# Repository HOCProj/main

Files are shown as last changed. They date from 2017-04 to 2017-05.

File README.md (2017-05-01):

**HOC Project**

*Hutchins-O'Dell-Cooper Senior Design Project Repository*

This project uses the following libraries and guides:

Adafruit MCP3008 library:
https://github.com/adafruit/Adafruit_Python_MCP3008

Twython AND Oauth:
https://www.raspberrypi.org/learning/getting-started-with-the-twitter-api/requirements/software/
https://www.raspberrypi.org/forums/viewtopic.php?t=162900&p=1054189

AVRDude:
http://www.raspihub.com/go/4c3370e8431b091c1698106135127581a646f3e2829fc26123d2bbfb34199dfa

SSMPT (Send email):
http://stackoverflow.com/questions/38391412/raspberry-pi-send-mail-from-command-line-using-gmail-smtp-server

Fetchmail (Receive email):
http://www.raspberry-projects.com/pi/software_utilities/email/fetchmail-to-receive-email

These libraries will be automatically downloaded and installed by executing the GitAll.py file. After installation, some parts require additional setup. Refer to the corresponding guide.

**User Manual**

Setup guides and example scripts are available in the appropriate folders (Raspberry Pi and ATTiny85).

The primary purpose of our project is to provide a cheap means of extending the capabilities of the Raspberry Pi and the ATTiny85. We also have the secondary purpose of compiling all of the necessary software and troubleshooting into one location, so that a person with beginner-intermediate level experience with circuitry and code can avoid the wiring mess of traditional electronics and the days or weeks of research into software.

On the board is a 40-pin header. This is used to connect our project to the Raspberry Pi. Doing so gives the Pi access to an MCP3008 ADC and an external power supply. There is also an 8-pin socket for an ATTiny85, which can be connected and interfaced with the IR receiver and the external power supply and ADC as well. The Raspberry Pi and ATTiny85 can be used simultaneously or separately. If using both of them and the ADC for either (cannot be used by both at one time), you must be mindful of shared connections. Refer to the board schematics.

A green screw block connector is situated next to the IR receiver. This can be used to receive external power (up to 33V and 3A continuous), and regulate it to ~5V for the Pi and ATTiny. Next to that is an 8-pin straight header. These are the analog inputs for the ADC, corresponding to channels 0-7. Next to that is a 2x4-pin header, which is laid out exactly the same as the ATTiny85 pins and is used to access those pins. Below that is a button which resets the ATTiny85 (pulls the RESET pin to ground).

There are two 2-pin headers, each labeled RPi and MCP. These are used to connect and disconnect power to the Raspberry Pi and MCP3008 respectively. If, for example, you want the ATTiny and Raspberry Pi to communicate over the ISP lines, the MCP header should be disconnected to prevent that chip from interfering with the signals. Or if you want the ATTiny to use the ADC and the Pi is not in use or powered separately, the RPi header should be disconnected.]

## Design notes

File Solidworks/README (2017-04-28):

This folder contains Solidworks and .STL models of the case parts.

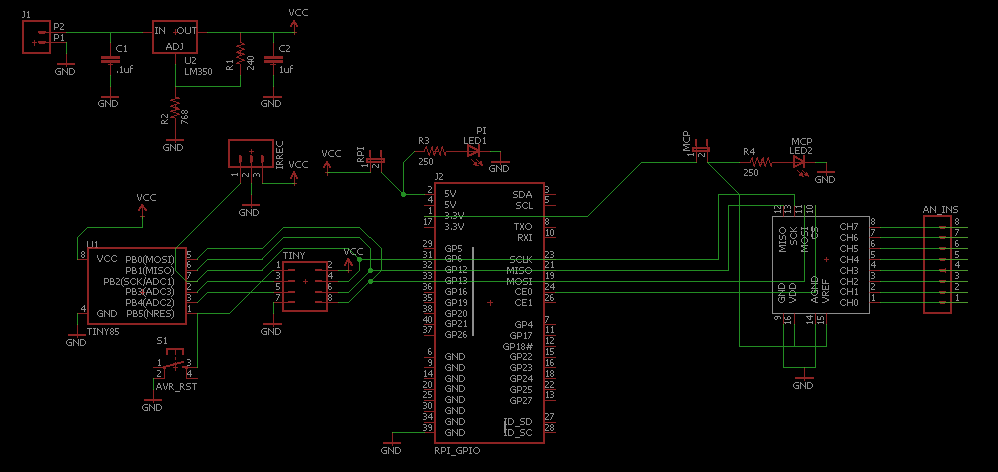
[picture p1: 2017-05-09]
Schematic Rev 2.png

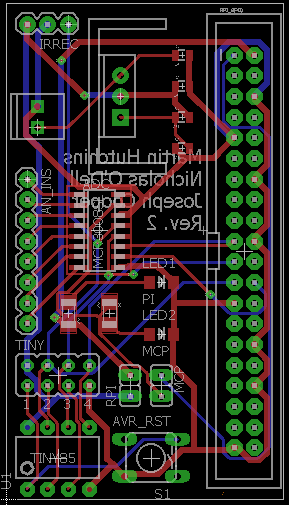
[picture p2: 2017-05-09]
Board Rev 2.png

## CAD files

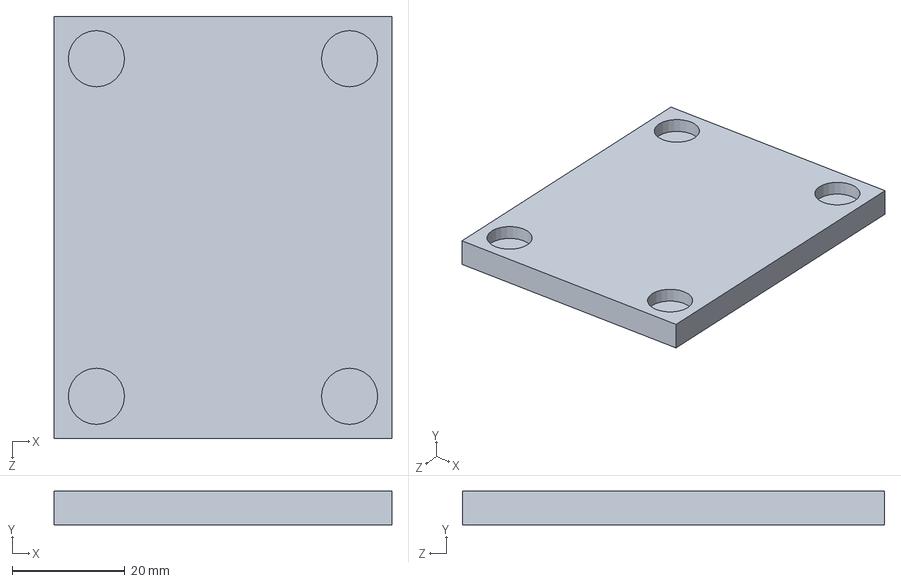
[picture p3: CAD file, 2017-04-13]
Solidworks/top.SLDPRT
60.0 x 6.00 x 75.0 mm

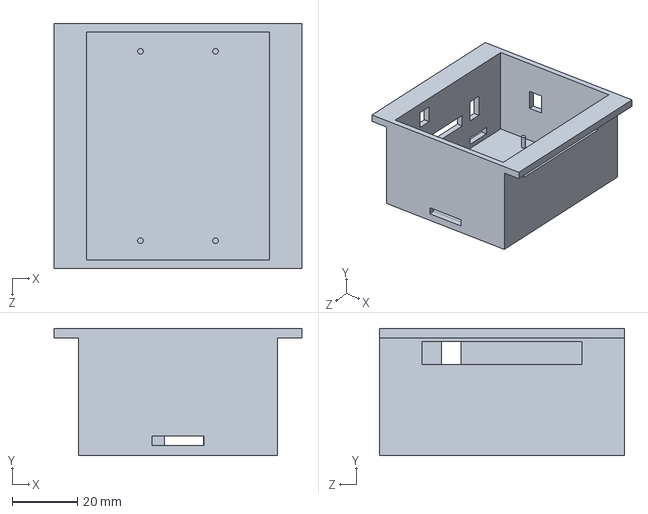
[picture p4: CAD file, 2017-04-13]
Solidworks/part 2 with pegs.SLDPRT
76.0 x 39.0 x 75.0 mm

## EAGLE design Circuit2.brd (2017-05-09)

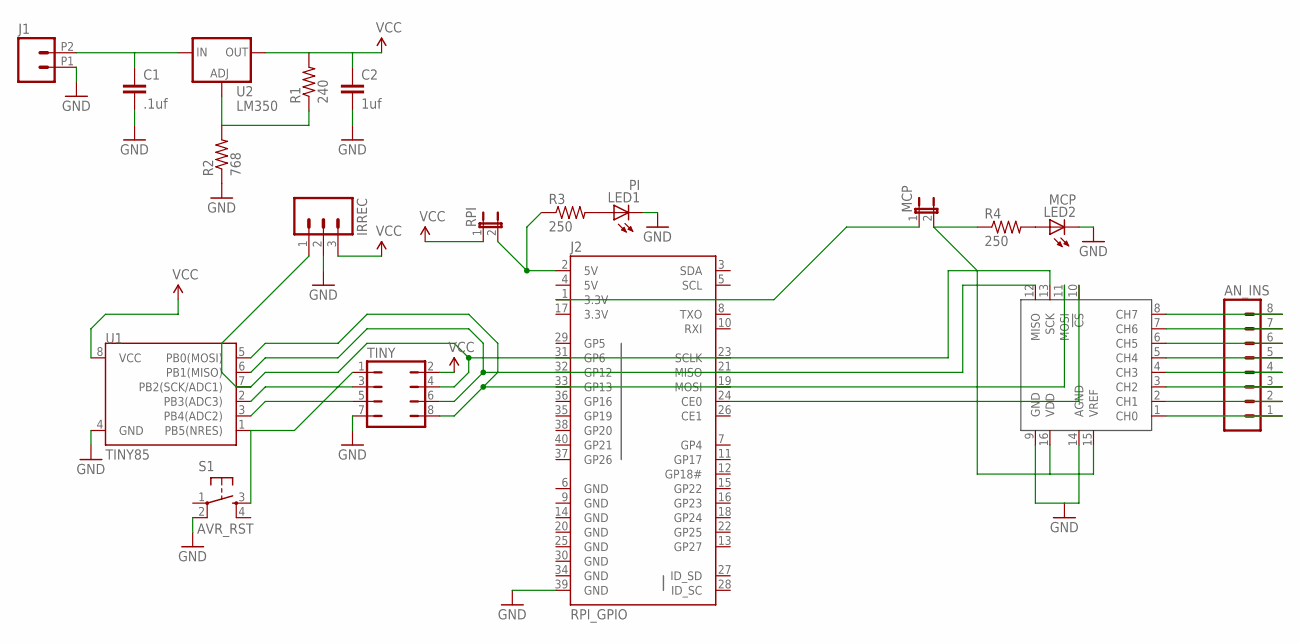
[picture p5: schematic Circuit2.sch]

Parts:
ADC: MCP3008SL; SO16
AN_INS: M08; 1X08_ROUND
C1: .1uf; 0805
C2: 1uf; 0805
IRREC: M03PTH; 1X03
J1: M022.54MM_SCREWTERM; 1X02_2.54_SCREWTERM
J2: RPI_GPIO; 2X20-SHROUDED
LED1: PI; LED-1206
LED2: MCP; LED-1206
MCP: JP1E; JP1
R1: 240; 0805
R2: 768; 0805
R3, R4: 250; 1206
RPI: JP1E; JP1
S1: AVR_RST; TAC-SWITCH-PTH
TINY: JP4Q
U1: TINY85; DIP08
U2: LM350; TO220-ADJ

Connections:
3.3V: J2.17 (3.3V)
5V: J2.4 (5V)
GND: ADC.9 (GND), ADC.14 (AGND), C1.2, C2.2, IRREC.2, J1.P1 (1), J2.6 (GND), J2.9 (GND), J2.14 (GND), J2.20 (GND), J2.25 (GND), J2.30 (GND), J2.34 (GND), J2.39 (GND), LED1.C, LED2.C, R2.1, S1.2, TINY.7, U1.4 (GND)
unnamed: ADC.11 (MOSI), J2.19 (MOSI), TINY.8, U1.5 (PB0(MOSI))
unnamed: ADC.12 (MISO), J2.21 (MISO), TINY.6, U1.6 (PB1(MISO))
unnamed: ADC.13 (SCK), IRREC.1, J2.23 (SCLK), TINY.4, U1.7 (PB2(SCK/ADC1))
unnamed: J2.2 (5V), R3.1, RPI.2
unnamed: TINY.3, U1.2 (PB3(ADC3))
unnamed: S1.3, TINY.1, U1.1 (PB5(NRES))
unnamed: TINY.5, U1.3 (PB4(ADC2))
unnamed: ADC.15 (VREF), ADC.16 (VDD), MCP.2, R4.1
unnamed: R1.1, R2.2, U2.ADJ
unnamed: ADC.8 (CH7), AN_INS.8
unnamed: C1.1, J1.P2 (2), U2.IN
unnamed: ADC.10 (!CS), J2.24 (CE0)
unnamed: J2.1 (3.3V), MCP.1
unnamed: ADC.7 (CH6), AN_INS.7
unnamed: ADC.6 (CH5), AN_INS.6
unnamed: ADC.5 (CH4), AN_INS.5
unnamed: ADC.4 (CH3), AN_INS.4
unnamed: ADC.3 (CH2), AN_INS.3
unnamed: ADC.2 (CH1), AN_INS.2
unnamed: ADC.1 (CH0), AN_INS.1
unnamed: LED1.A, R3.2
unnamed: LED2.A, R4.2
VCC: C2.1, IRREC.3, R1.2, RPI.1, TINY.2, U1.8 (VCC), U2.OUT

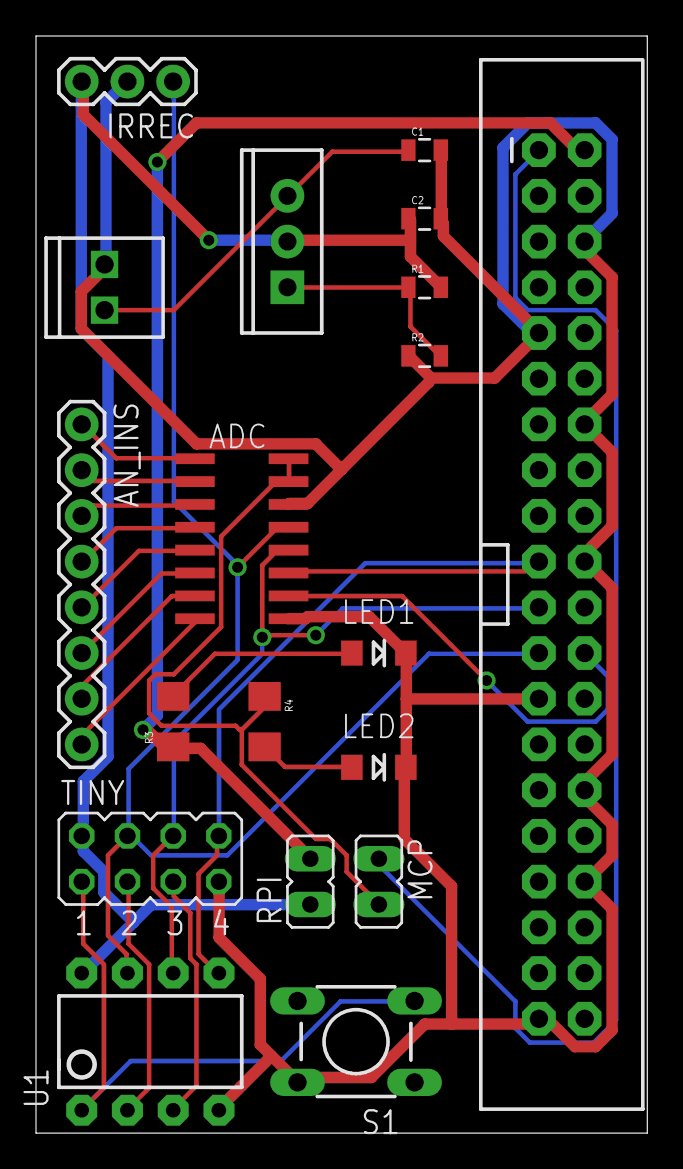
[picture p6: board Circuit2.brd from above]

Board: 2 copper layers, 34.0 x 61.0 mm, 19 parts (0 on the bottom side), 24 nets.

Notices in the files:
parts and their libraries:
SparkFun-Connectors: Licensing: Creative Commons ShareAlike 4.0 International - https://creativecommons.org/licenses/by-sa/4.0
